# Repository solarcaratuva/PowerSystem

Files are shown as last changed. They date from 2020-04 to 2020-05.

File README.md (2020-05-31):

# PowerSystem
Developing PCB for Power System and ECU code for STM32F413ZH.

## PCB Design
TODO:
1) ~Remove double throw 12V power relay off PCB (as it is chasis mount)~
2) ~Add charge and discharge relays to PCB~
3) ~Figure out which pins on the STM to use for what~
4) ~Add extra CAN port (need one for Rx from BMS, and one for Tx and Rx to other PCBs) as well as the external CAN Tranceivers~
5) ~Make sure everything has footprint and 3d model~
6) Pick out exact voltage regulator models
7) Layout board

## STM 32 & ECU Code
TODO:
1) Figure out which pins on the STM to use for what
2) Figure out what each power supply input (VDD, VSS, VBAT, VDDUSB, VDDA, VSSA) and other important inputs are for 

Pin Names used by MbedOS:
https://os.mbed.com/platforms/ST-Nucleo-F413ZH/

Important pins for us:

| STM Pin Name | MbedOS Pin Name(s) | Function |
| :---: | :---: | :--- |
| PB0 | `PB_0`/`LED1` | BMS Error |
| PB7 | `PB_7`/`LED2` | CAN Error |
| PB14 | `PB_14`/`LED3` | Unused LED |
| PC13 | `PC_13`/`BUTTON1` | Unused Button |
| PD0 | `PD_0` | CAN1 (BMS) Receivier |
| PD1 | `PD_1` | CAN1 (BMS) Transmitter |
| PB12 | `PB_12` | CAN2 (Main) Receivier |
| PB13 | `PB_13` | CAN2 (Main) Transmitter |
| PG9 | `PG_9`/`D0` | DC-DC ON |
| PG14 | `PG_14`/`D1` | Unused Digital I/O |
| PF15 | `PF_15`/`D2` | Unused Digital I/O |
| PE13 | `PE_13`/`D3` | Unused Digital I/O |
| PF14 | `PF_14`/`D4` | Unused Digital I/O |
| PE11 | `PE_11`/`D5` | Unused Digital I/O |
| PE9 | `PE_9`/`D6` | Unused Digital I/O |
| PF13 | `PF_13`/`D7` | Unused Digital I/O |
| PF12 | `PF_12`/`D8` | Unused Digital I/O |
| PD15 | `PD_15`/`D9` | Unused Digital I/O |
| PD14 | `PD_14`/`D10` | Unused Digital I/O |
| PA7 | `PA_7`/`D11` | Unused Digital I/O |
| PA6 | `PA_6`/`D12` | Unused Digital I/O |
| PA5 | `PA_5`/`D13` | Unused Digital I/O |
| PB9 | `PB_9`/`D14` | Unused Digital I/O |
| PB8 | `PB_8`/`D15` | Unused Digital I/O |
| PA3 | `PA_3`/`A0` | AUX Voltage |
| PC0 | `PC_0`/`A1` | DC-DC Voltage |
| PC3 | `PC_3`/`A2` | Unused Analog I/O |
| PC1 | `PC_1`/`A3` | Unused Analog I/O |
| PC4 | `PC_4`/`A4` | Unused Analog I/O |
| PC5 | `PC_5`/`A5` | Unused Analog I/O |

Note: the LEDs for Power ON, AUX ON, DC-DC ON, and AUX/DC-DC being used can be directly connected to the power supply / relay driving it.

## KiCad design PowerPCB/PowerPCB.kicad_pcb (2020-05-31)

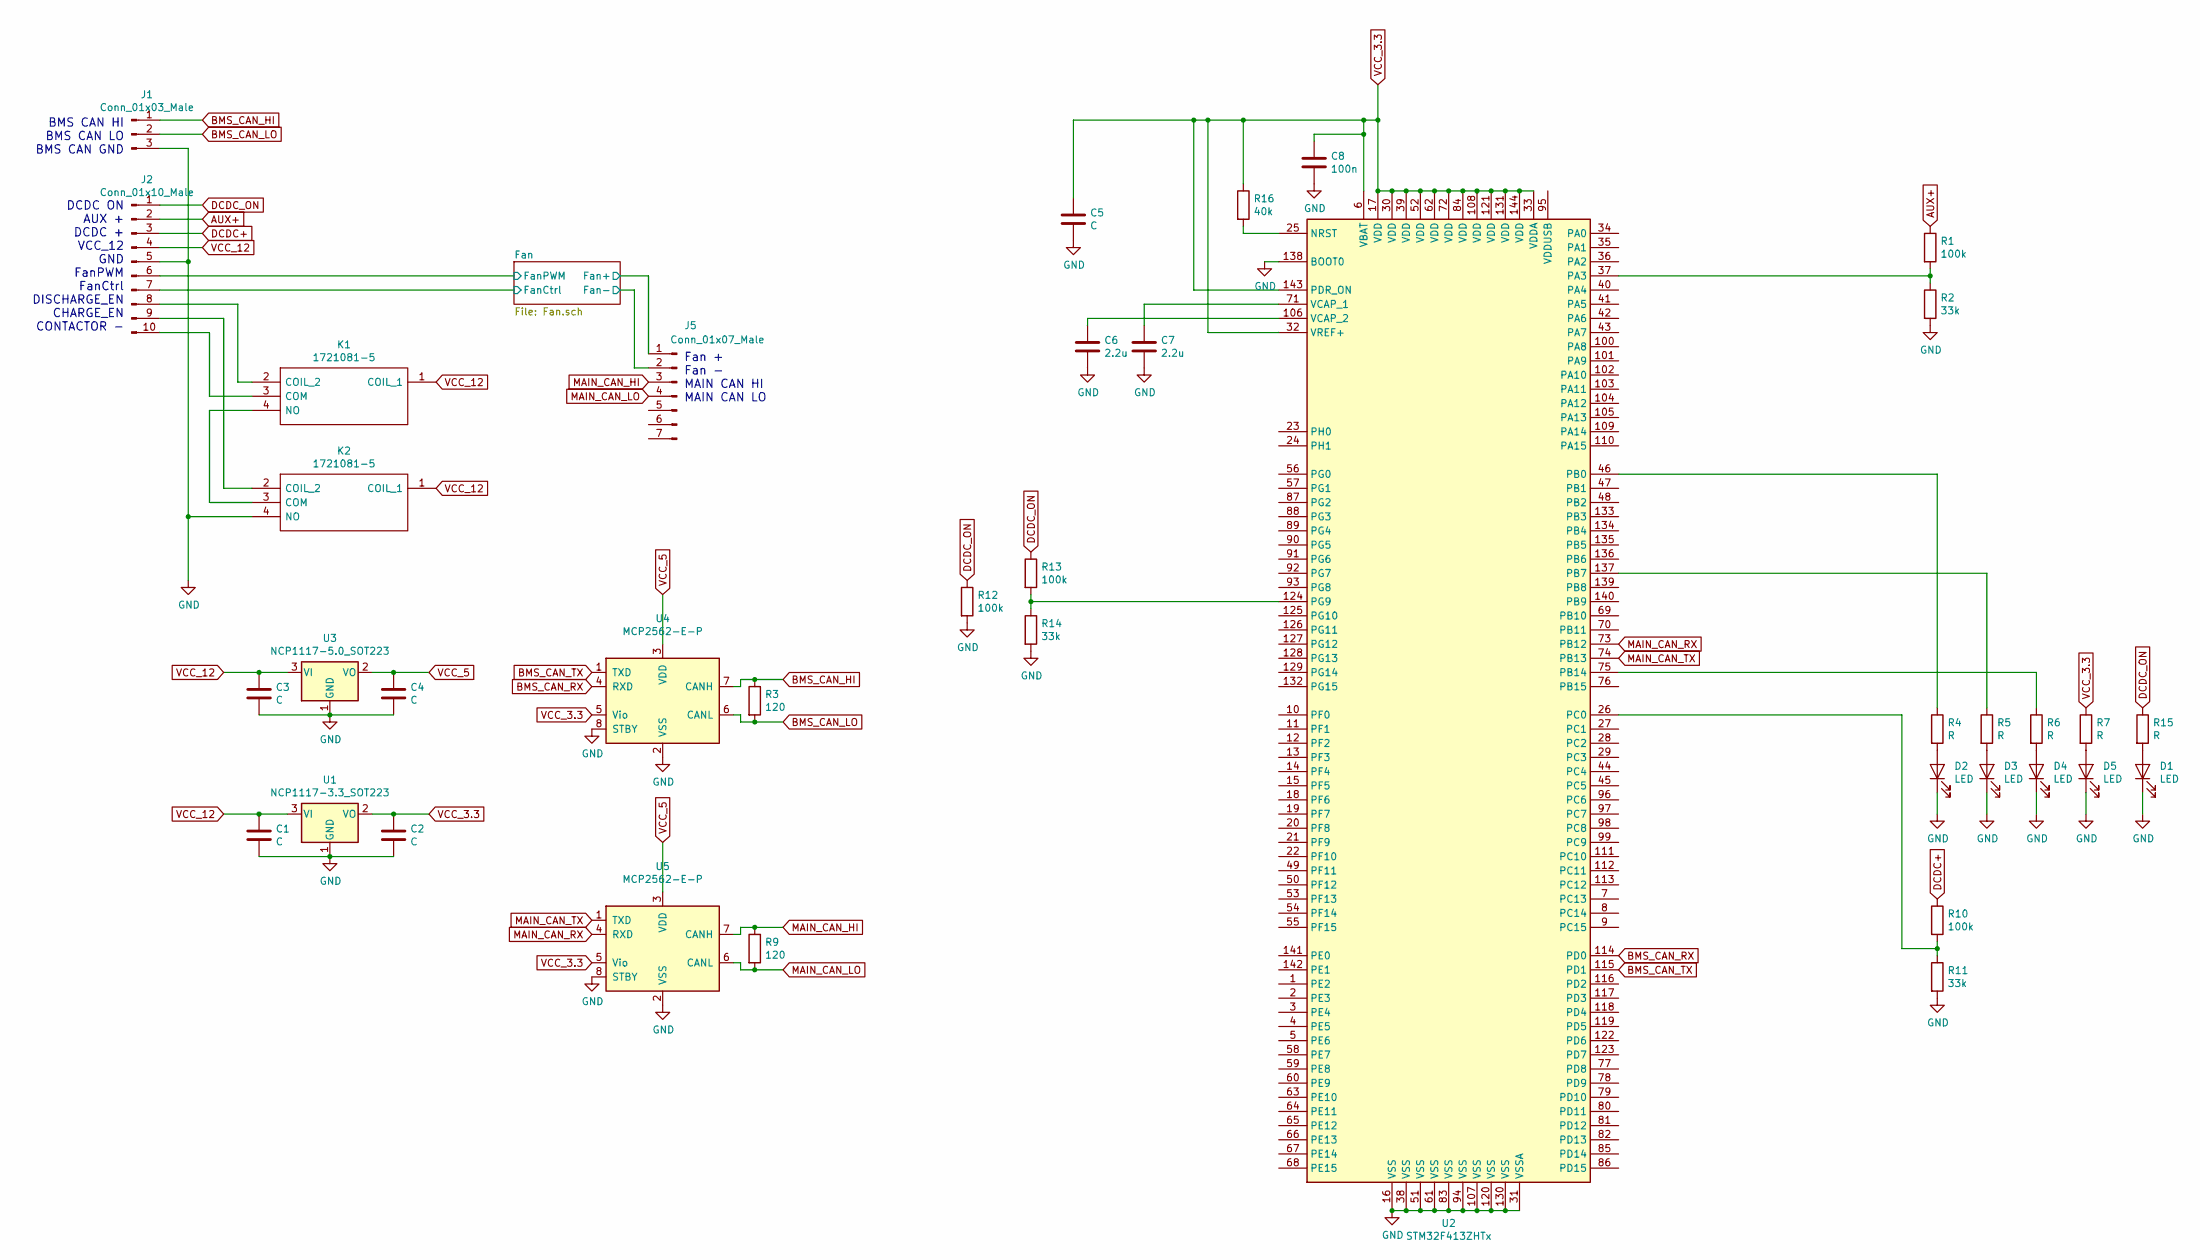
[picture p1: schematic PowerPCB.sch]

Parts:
C1, C2, C3, C4, C5: C; C_0805_2012Metric_Pad1.15x1.40mm_HandSolder
C6, C7: 2.2u; C_0805_2012Metric_Pad1.15x1.40mm_HandSolder
C8: 100n; C_0805_2012Metric_Pad1.15x1.40mm_HandSolder
D1, D2, D3, D4, D5: LED; LED_0805_2012Metric_Pad1.15x1.40mm_HandSolder
J1: Conn_01x03_Male; PinHeader_1x03_P2.54mm_Horizontal
J2: Conn_01x10_Male; PinHeader_1x10_P2.54mm_Horizontal
J5: Conn_01x07_Male; PinHeader_1x07_P2.54mm_Horizontal
K1, K2: 1721081-5; 17210815; Mouser Part Number 655-1721081-5
R1, R10, R12, R13: 100k; R_0805_2012Metric_Pad1.15x1.40mm_HandSolder
R2, R11, R14: 33k; R_0805_2012Metric_Pad1.15x1.40mm_HandSolder
R3, R9: 120; R_0805_2012Metric_Pad1.15x1.40mm_HandSolder
R4, R5, R6, R7, R15: R; R_0805_2012Metric_Pad1.15x1.40mm_HandSolder
R16: 40k; R_0805_2012Metric_Pad1.15x1.40mm_HandSolder
U1: NCP1117-3.3_SOT223; SOT-223-3_TabPin2
U2: STM32F413ZHTx; LQFP-144_20x20mm_P0.5mm
U3: NCP1117-5.0_SOT223; SOT-223-3_TabPin2
U4, U5: MCP2562-E-P; DIP-8_W7.62mm

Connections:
/Fan/Fan+: J5.1; also elsewhere on the board
/Fan/Fan-: J5.2; also elsewhere on the board
/Fan/FanCtrl: J2.7; also elsewhere on the board
/Fan/FanPWM: J2.6; also elsewhere on the board
AUX+: J2.2, R1.1
BMS_CAN_HI: J1.1, R3.1, U4.7 (CANH)
BMS_CAN_LO: J1.2, R3.2, U4.6 (CANL)
BMS_CAN_RX: U2.114 (PD0), U4.4 (RXD)
BMS_CAN_TX: U2.115 (PD1), U4.1 (TXD)
DCDC+: J2.3, R10.1
DCDC_ON: J2.1, R12.1, R13.1, R15.1
GND: C1.2, C2.2, C3.2, C4.2, C5.2, C6.2, C7.2, C8.2, D1.1 (K), D2.1 (K), D3.1 (K), D4.1 (K), D5.1 (K), J1.3, J2.5, K2.4 (NO), R2.2, R11.2, R12.2, R14.2, U1.1 (GND), U2.16 (VSS), U2.31 (VSSA), U2.38 (VSS), U2.51 (VSS), U2.61 (VSS), U2.83 (VSS), U2.94 (VSS), U2.107 (VSS), U2.120 (VSS), U2.130 (VSS), U2.138 (BOOT0), U3.1 (GND), U4.2 (VSS), U4.8 (STBY), U5.2 (VSS), U5.8 (STBY); also elsewhere on the board
MAIN_CAN_HI: J5.3, R9.1, U5.7 (CANH)
MAIN_CAN_LO: J5.4, R9.2, U5.6 (CANL)
MAIN_CAN_RX: U2.73 (PB12), U5.4 (RXD)
MAIN_CAN_TX: U2.74 (PB13), U5.1 (TXD)
unnamed: C6.1, U2.106 (VCAP_2)
unnamed: C7.1, U2.71 (VCAP_1)
unnamed: D1.2 (A), R15.2
unnamed: D2.2 (A), R4.2
unnamed: D3.2 (A), R5.2
unnamed: D4.2 (A), R6.2
unnamed: D5.2 (A), R7.2
unnamed: J2.8, K1.2 (COIL_2)
unnamed: J2.9, K2.2 (COIL_2)
unnamed: J2.10, K1.3 (COM)
unnamed: K1.4 (NO), K2.3 (COM)
unnamed: R1.2, R2.1, U2.37 (PA3)
unnamed: R4.1, U2.46 (PB0)
unnamed: R5.1, U2.137 (PB7)
unnamed: R6.1, U2.75 (PB14)
unnamed: R10.2, R11.1, U2.26 (PC0)
unnamed: R13.2, R14.1, U2.124 (PG9)
unnamed: R16.2, U2.25 (NRST)
VCC_3.3: C2.1, C5.1, C8.1, R7.1, R16.1, U1.2 (VO), U2.6 (VBAT), U2.17 (VDD), U2.30 (VDD), U2.32 (VREF+), U2.33 (VDDA), U2.39 (VDD), U2.52 (VDD), U2.62 (VDD), U2.72 (VDD), U2.84 (VDD), U2.108 (VDD), U2.121 (VDD), U2.131 (VDD), U2.143 (PDR_ON), U2.144 (VDD), U4.5 (Vio), U5.5 (Vio)
VCC_5: C4.1, U3.2 (VO), U4.3 (VDD), U5.3 (VDD)
VCC_12: C1.1, C3.1, J2.4, K1.1 (COIL_1), K2.1 (COIL_1), U1.3 (VI), U3.3 (VI); also elsewhere on the board

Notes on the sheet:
BMS CAN HI BMS CAN LO BMS CAN GND
DCDC ON AUX + DCDC + VCC_12 GND FanPWM FanCtrl DISCHARGE_EN CHARGE_EN CONTACTOR -
Fan + Fan - MAIN CAN HI MAIN CAN LO

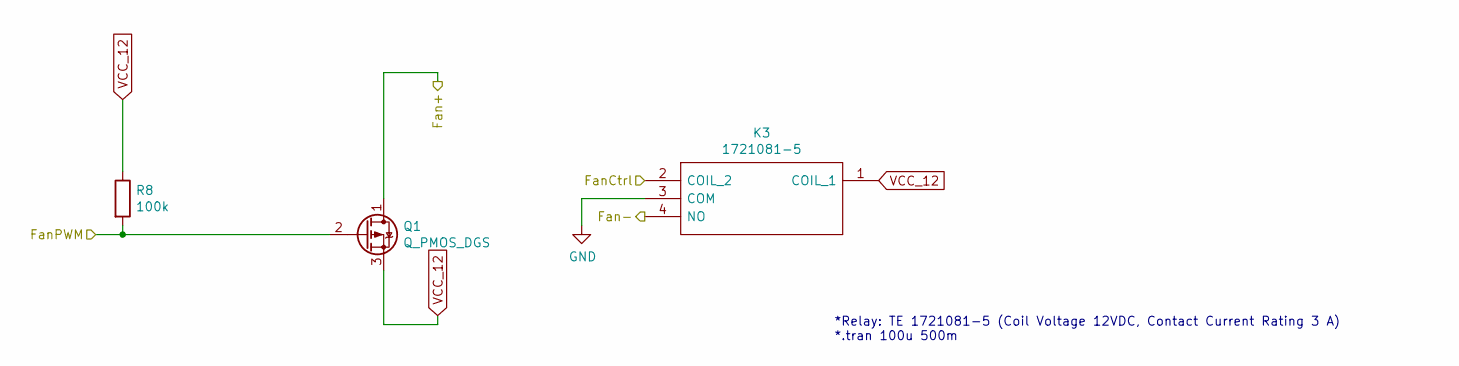
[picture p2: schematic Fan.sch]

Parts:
K3: 1721081-5; 17210815; Mouser Part Number 655-1721081-5
Q1: Q_PMOS_DGS; SOT-323_SC-70_Handsoldering
R8: 100k; R_0805_2012Metric_Pad1.15x1.40mm_HandSolder

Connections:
/Fan/Fan+: Q1.1 (D); also elsewhere on the board
/Fan/Fan-: K3.4 (NO); also elsewhere on the board
/Fan/FanCtrl: K3.2 (COIL_2); also elsewhere on the board
/Fan/FanPWM: Q1.2 (G), R8.2; also elsewhere on the board
GND: K3.3 (COM); also elsewhere on the board
VCC_12: K3.1 (COIL_1), Q1.3 (S), R8.1; also elsewhere on the board

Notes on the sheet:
*Relay: TE 1721081-5 (Coil Voltage 12VDC, Contact Current Rating 3 A) *.tran 100u 500m

Board: 2 copper layers, 41 parts (0 on the bottom side), 37 nets, no tracks yet.

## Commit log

2020-04-05 Initial Power PCB
    [PowerPCB.kicad_pcb, PowerPCB.sch]
2020-04-05 Power PCB connector
    [PowerPCB.sch]
2020-04-12 Added inital components
    [PowerPCB.sch]
2020-04-12 Added Fan Components
    [Fan.kicad_pcb, Fan.sch]
2020-04-12 Added Fan Testing Circuit
    [Fan.sch, PowerPCB.sch]
2020-04-16 more fan changes
    [Fan.sch]
2020-04-16 Added test PCB to test simulator
    [Fan.sch, Test.kicad_pcb, Test.sch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]
2020-04-19 Added Multisim File for testing Fan Circuitry and MOSFET spice models
    [Fan.sch, Test.sch]
2020-04-26 Added Voltage Divider to PowerPCB for stepping down AUX voltage before outputting it to STM
    [PowerPCB.sch]
2020-05-02 added fan system
    [Fan.kicad_pcb, Fan.sch]
2020-05-03 Added Multisim file to test input protection circuitry suggested by Digikey
2020-05-11 moved protection circuit into KiCad
    [LongWireSwitching.sch, MicroController.sch, PCB_Protection.kicad_pcb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]
2020-05-11 made all paths to spice models relative and renumbered pins of MOSFETs in Fan
    [Fan.sch, MicroController.sch, PCB_Protection.sch]
2020-05-11 Cleaned up Fan Schematic
    [Fan.sch]
2020-05-11 Made all file paths use forward slashes
    [Fan.sch, MicroController.sch, PCB_Protection.sch]
2020-05-11 Changed spice model for p-channel mosfet
    [Fan.sch]
2020-05-17 Added Fan circuit as hierarchical block to main PCB
    [Fan.sch, PowerPCB.sch]
2020-05-24 new relay added to PowerPCB, and its 3D model is added to the library
    [Fan.sch]
2020-05-24 added SamacSys Folder, project level footprint references in powerPCB
2020-05-24 Added footprints for all components
    [Fan.sch, PowerPCB.sch]
2020-05-24 Imported components to PCBnew
    [PowerPCB.sch]
2020-05-29 Added TODO list and STM Pin Names Table to Readme
2020-05-29 Added 3A SPST relays for all relays
    [Fan.sch, PowerPCB.sch]
2020-05-30 Removed SPDT chassis mount relay, added diode footprint
    [Fan.sch, PowerPCB.sch]
2020-05-30 Added Charge and Discharge relays
    [Fan.sch, PowerPCB.sch]
2020-05-31 Removed power diode (will be external) and unnecessary grounds
    [PowerPCB.sch]
2020-05-31 Cleaned up main schematic and corrected text for fan relay
    [Fan.sch, PowerPCB.sch]
2020-05-31 Added CAN connections to STM
    [PowerPCB.kicad_pcb, PowerPCB.sch]
2020-05-31 Added LED connections to STM
    [PowerPCB.sch]
2020-05-31 Added AUX+ and DCDC+ as analog inputs
    [PowerPCB.kicad_pcb, PowerPCB.sch]
2020-05-31 Finished connections to STM, exported to PCBnew
    [PowerPCB.kicad_pcb, PowerPCB.sch]
2020-06-11 Added input protection circuitry as sub-schematic
    [Fan.sch, InputProtection.sch, PowerPCB.sch]
2020-06-11 Added footprints for resistors and capacitors
    [InputProtection.sch]
2020-06-13 Changed Shottky diodes to 0805 size
    [InputProtection.sch]
2020-06-13 moved all PowerCode into separate repo
2020-06-14 Added bypass capacitors to CAN transceivers
    [Fan.sch, InputProtection.sch, PowerPCB.sch]
2020-06-14 Changed Shottky diode footprint to read text better
2020-06-14 Moved text of Shottky diodes so it is readable
2020-06-20 Edited footprint of Shottky diodes to have smaller font sizes
2020-07-13 Added VDD bypass capacitors and values for all components
    [Fan.sch, InputProtection.sch, PowerPCB.sch]
